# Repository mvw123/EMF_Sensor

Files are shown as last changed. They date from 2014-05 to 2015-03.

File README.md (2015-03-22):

EMF_Sensor
==========
Brief
-----
This is an open hardware design for an EMF sensor and transmitter circuit (sometimes known as a tone generator and detector, an ELF sensor, warbler or wire follower) which can be used to send a 2kHz audible tone down a wire with the transmitter and sense the presence of the wire with the receiver. It's main uses are for hidden wire and wire boundary detection. 

This is NOT for connection to LIVE mains or hazardous voltages - there are NO safety caps or safety barriers in the circuit. 

The circuit is created with Ki-CAD, an open source EDA tool for schematic capture and PCB layout. There are two boards in the design seperated by a snap off region. One for the transmitter, one for the receiver. The design should be battery powered from a 9v battery for each board.

The circuit is designed so that it can be used for other educational purposes and for general operational amplifier design. 

MVW

Details
-------
The PCB uses a mixture of through hole and SMD 1206 size components. These parts were chosen as a trade off between size and ease of fitting. Through hole axial leaded resistors and capacitors can be soldered onto the 1206 SMD pads if desired by soldering the parts vertically. SMD parts are used to reduce the PCB size which is the most costly part of the design. The PCB could have been smaller, but the aim is to allow beginners to be able to easily solder to the pads as well as experts. 

A Simetrix simulation file is included. Simetrix is a windows simulator which can be downloaded and used freely up to its node limit which is more than adequate for most situations. Please download and tweak it, i think you'll find some components are not entirely needed.

CAD B (Rev 0.02) [WORK IN PROGRESS] March 2014
-----------------------------
Schematic and PCB updated to fix bug stopping the wien bridge oscillator working
schematic and PCB updated to add an inline resistor for the voltage reference for one of the amplifiers
This version was edited using the 7-7-2013 BZR 4022 -stable build for windows which upgrades the PCB to a new type and renames its file extension. 
The Design would benefit from splitting into two seperate designs.
The circuit schematic pages need renaming to something more sensible. 
BOM not available

The design requires external parts not shown on the circuit schematic. eg:-
9v battery 
battery connector
2.5mm earphone adapter
wire - length TBD

CAD A (Rev 0.01) [NOT TESTED] March 2014
-----------------------------
First dev release, not tested - awaiting return of PCBs. 
Known bugs exist. 
The wien bridge oscillator is wired incorrectly.
The oscillator resistor/capacitor values need setting up (board released whilst the values are tweaked)

The board is being produced by oshpark which ships internationally. Price for the minimum 3 boards (in march 2014) is approximately $25

Ki-CAD created schematic, layout, gebers
Simetrix simulation file
BOM needs to be finalised.

Requires external parts not shown on the circuit schematic. eg
9v battery 
battery connector
2.5mm earphone adapter
wire - length TBD

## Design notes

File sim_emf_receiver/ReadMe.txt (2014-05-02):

simetrix simulation file
open file
select simulator menu, run.
This will show a graph of any voltage sensors shown on the circuit. 
you can place more voltage sensors with place, probe, voltage probe

MVW

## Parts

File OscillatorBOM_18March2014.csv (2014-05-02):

ref | value
BT201 | 9V_C
BT301 | 9V_C
C201 | 10n
C202 | 10n
C203 | 10n
C204 | 100uF
C205 | 100uF
C206 | 100uF
C301 | 0.01uF
C302 | 4.7pF
C303 | 220nF
C304 | 100uF
C305 | 1uF
C306 | 1uF
C307 | 1uF
C308 | 1.5nF
C309 | 20pF
P202 | CONN_2
P203 | CONN_2
P301 | CONN_2
P302 | CONN_2
R201 | 1k
R202 | 1k
R203 | 1k
R204 | 1k
R205 | 10k
R206 | 20k
R207 | 20k
R208 | 20k
R209 | 6.8k
R210 | 6.8k
R211 | 2k
R212 | 2k
R213 | 10R
R214 | 2k
R215 | 10R
R216 | 2k
R217 | 20k
R218 | 1k
R301 | 0R0
R302 | 1Meg
R303 | 22Meg
R304 | 4.7k
R305 | 1Meg
R306 | 1k
R307 | 22k
R308 | 47k
R309 | 1Meg
R310 | 100R
R311 | 1Meg
RV301 | 100k
SW201 | SPST
SW301 | SPST
U201 | TL072
U301 | TL072

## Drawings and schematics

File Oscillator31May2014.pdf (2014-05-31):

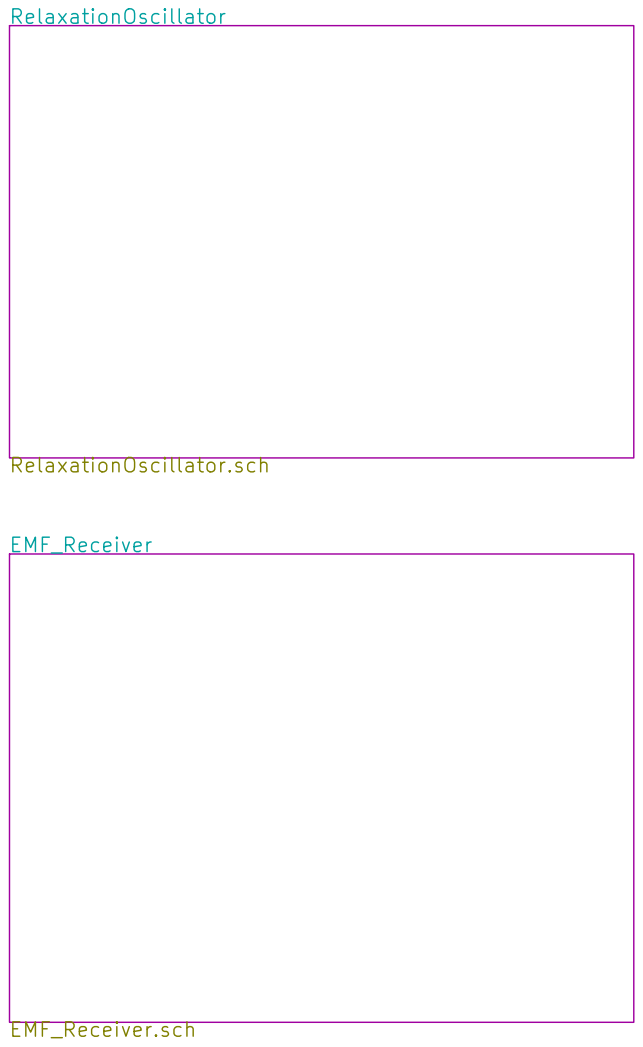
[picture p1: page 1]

Id: 1/3 Title: File: Oscillator.sch
Sheet: /

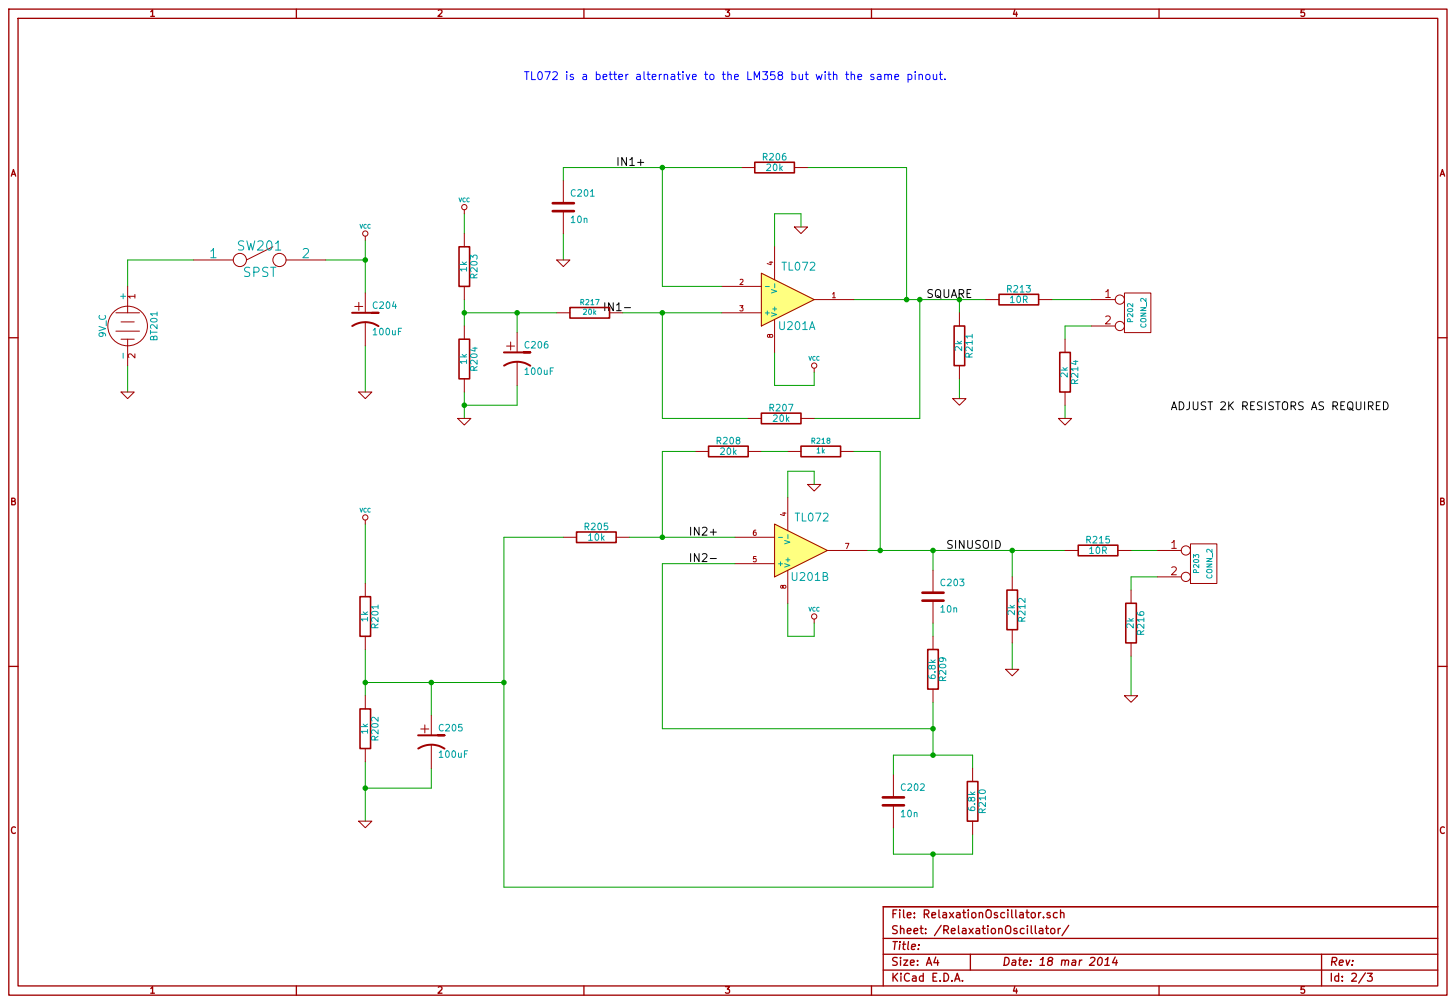
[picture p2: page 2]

TL072 is a better alternative to the LM358 but with the same pinout. VCC

Id: 2/3 Title: File: RelaxationOscillator.sch

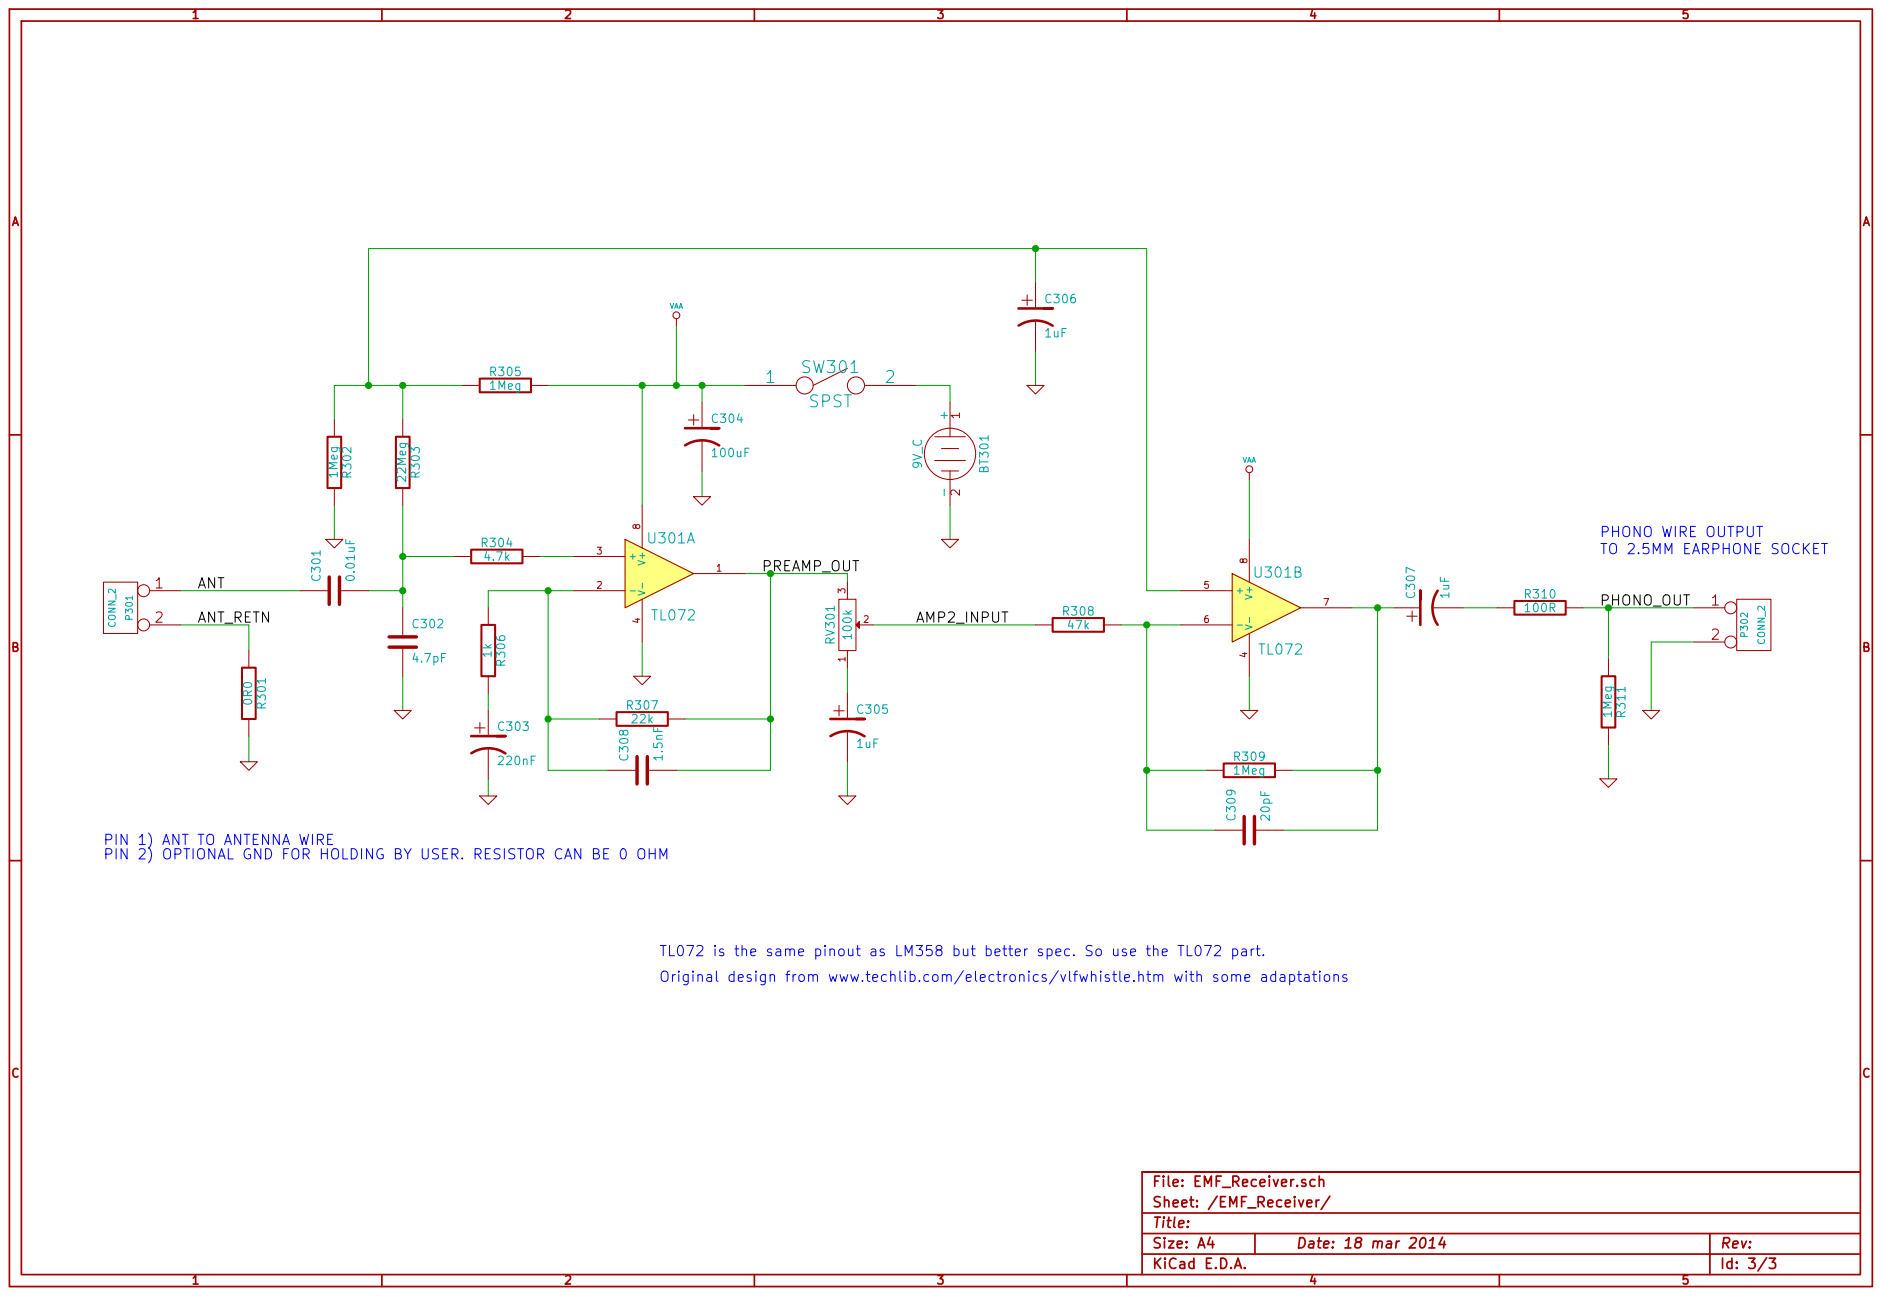
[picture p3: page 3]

Original design from www.techlib.com/electronics/vlfwhistle.htm with some adaptations 0R0 R301 1

PIN 1) ANT TO ANTENNA WIRE
PIN 2) OPTIONAL GND FOR HOLDING BY USER. RESISTOR CAN BE 0 OHM

Id: 3/3 Title: File: EMF_Receiver.sch
Sheet: /EMF_Receiver/

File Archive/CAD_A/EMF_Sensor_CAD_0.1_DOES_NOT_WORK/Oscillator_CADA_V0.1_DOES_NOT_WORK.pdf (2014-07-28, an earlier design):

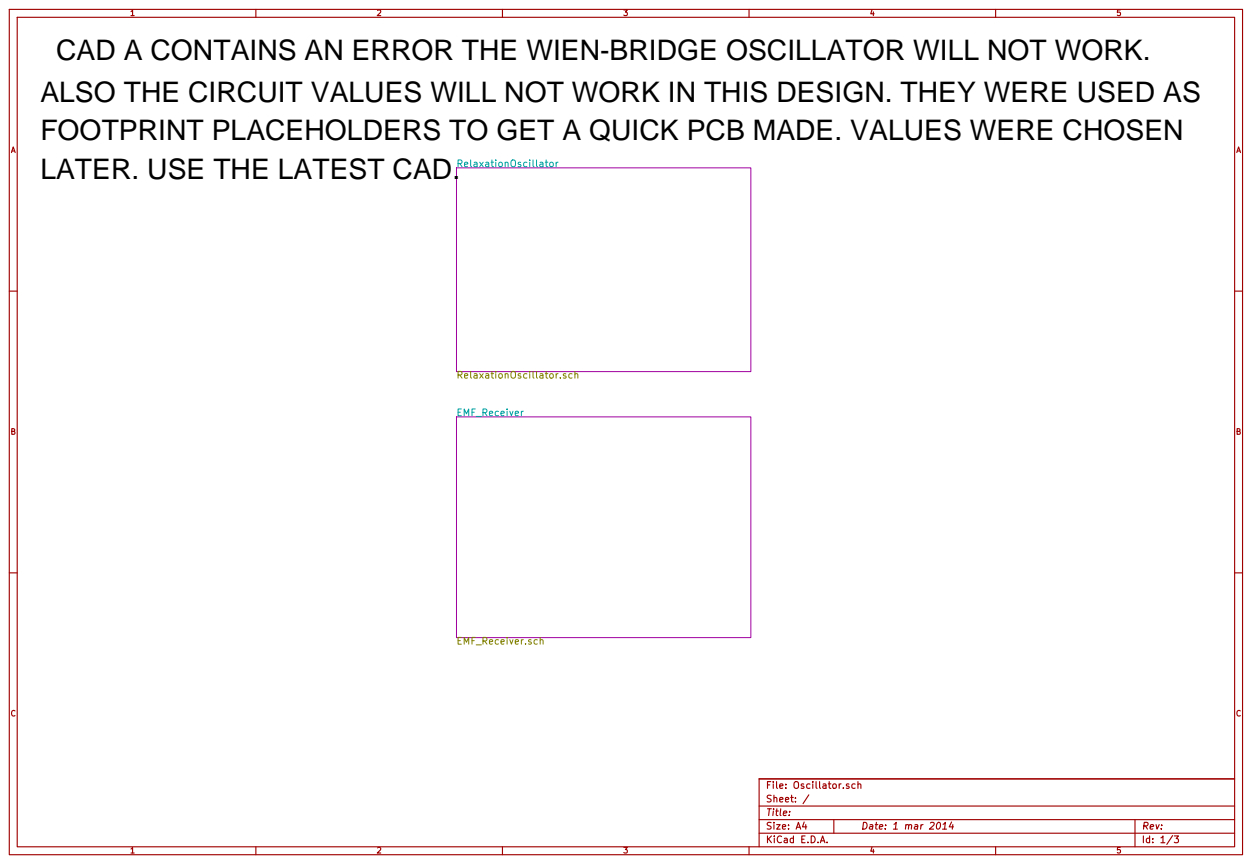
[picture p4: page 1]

Id: 1/3 Title: File: Oscillator.sch
Sheet: /

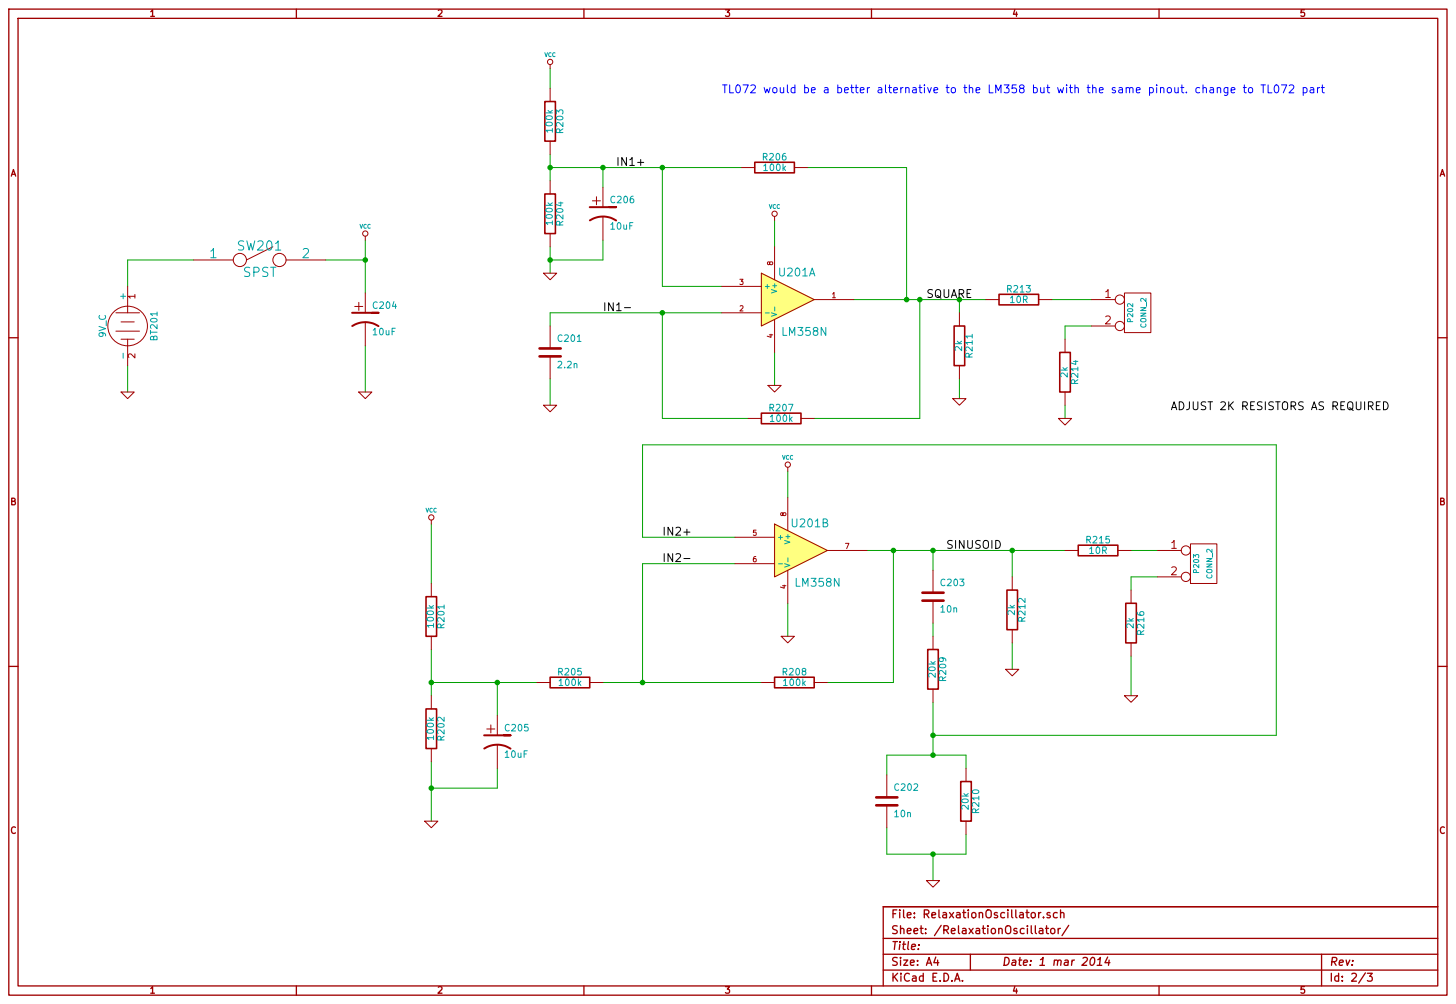
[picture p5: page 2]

TL072 would be a better alternative to the LM358 but with the same pinout. change to TL072 part VCC

Id: 2/3 Title: File: RelaxationOscillator.sch
Sheet: /RelaxationOscillator/

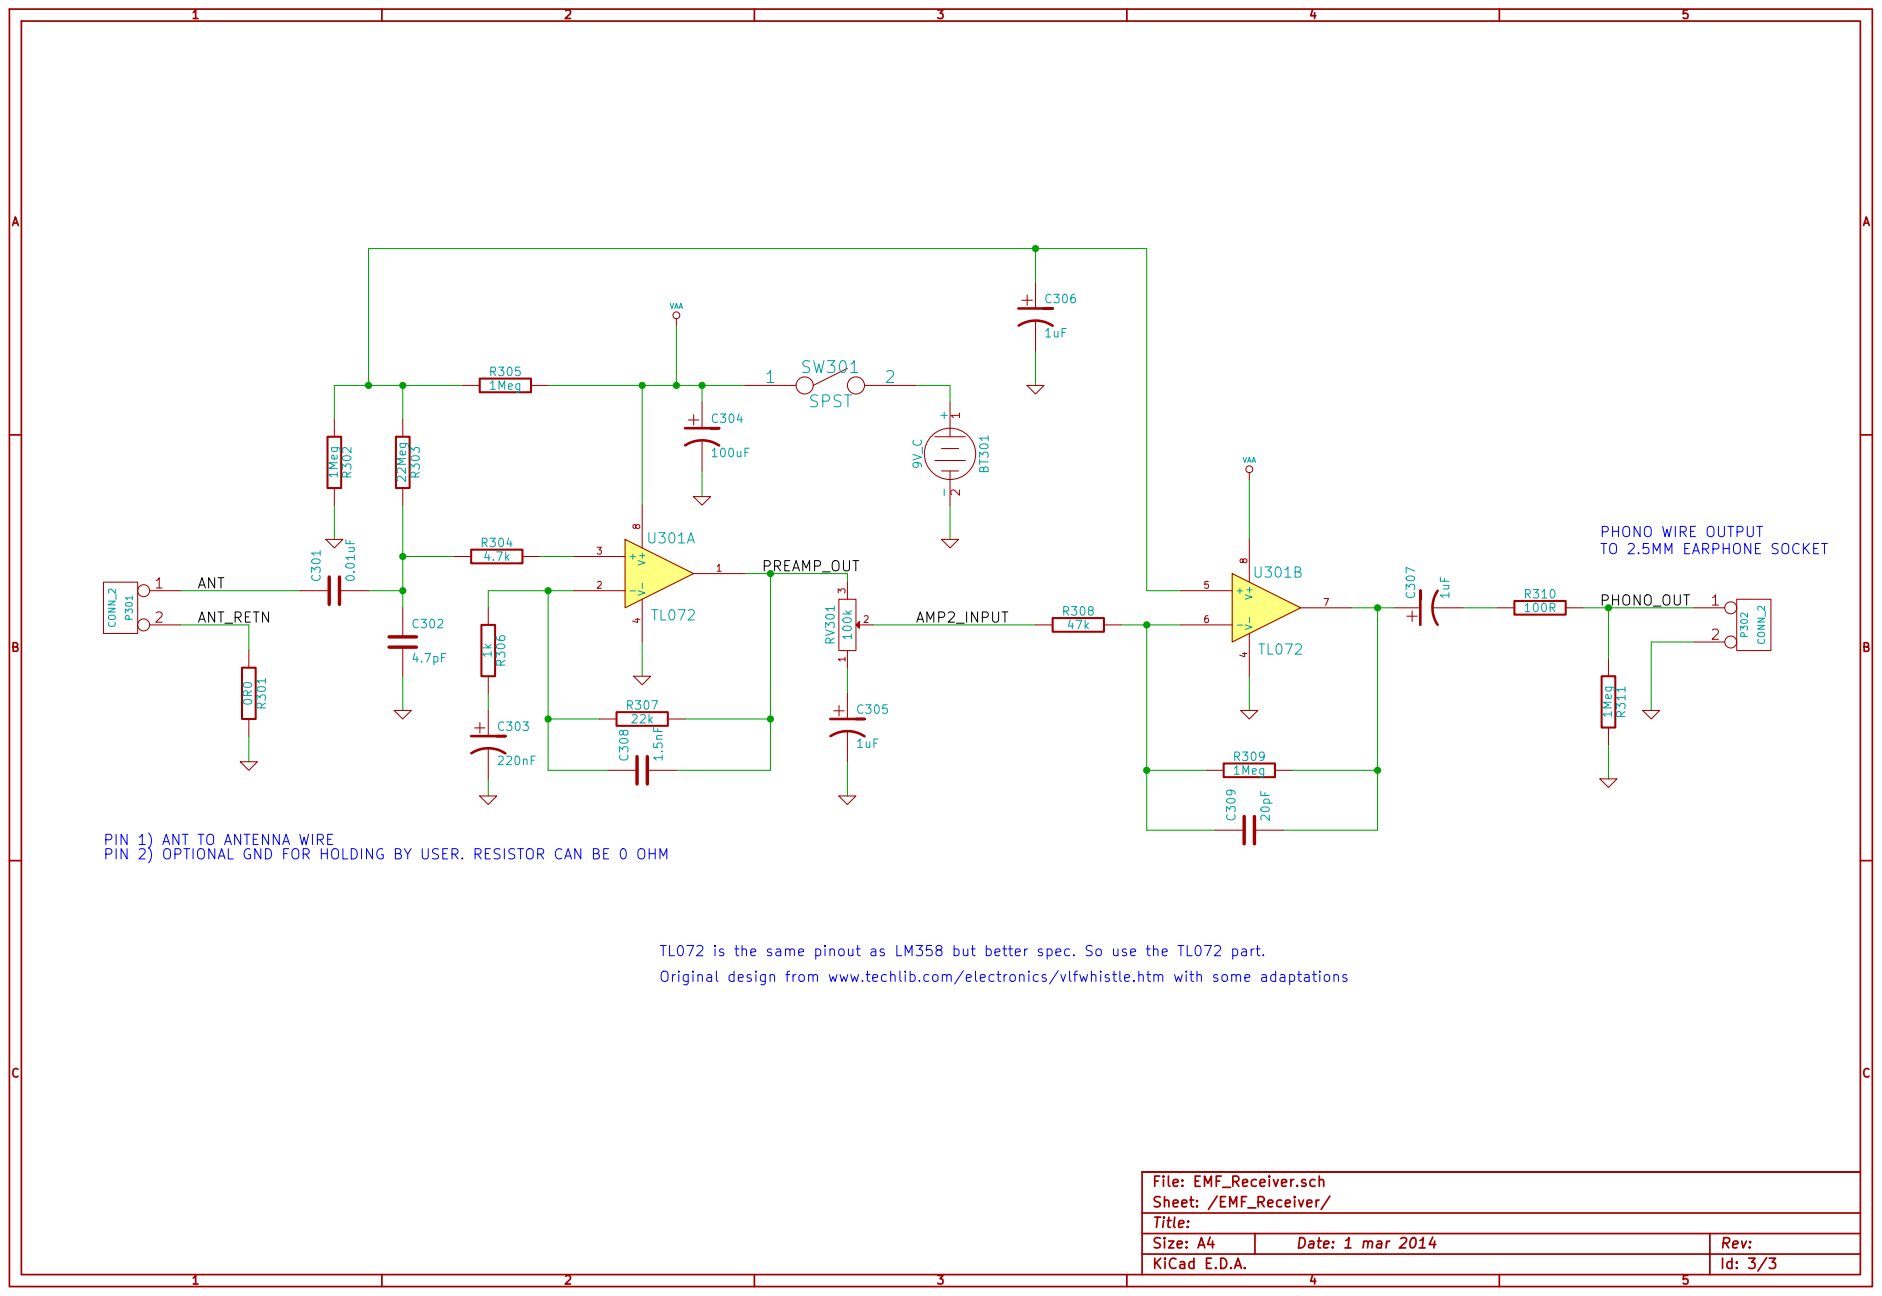
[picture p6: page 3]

Original design from www.techlib.com/electronics/vlfwhistle.htm with some adaptations 0R0 R301 1

PIN 1) ANT TO ANTENNA WIRE
PIN 2) OPTIONAL GND FOR HOLDING BY USER. RESISTOR CAN BE 0 OHM

Id: 3/3 Title: File: EMF_Receiver.sch
Sheet: /EMF_Receiver/

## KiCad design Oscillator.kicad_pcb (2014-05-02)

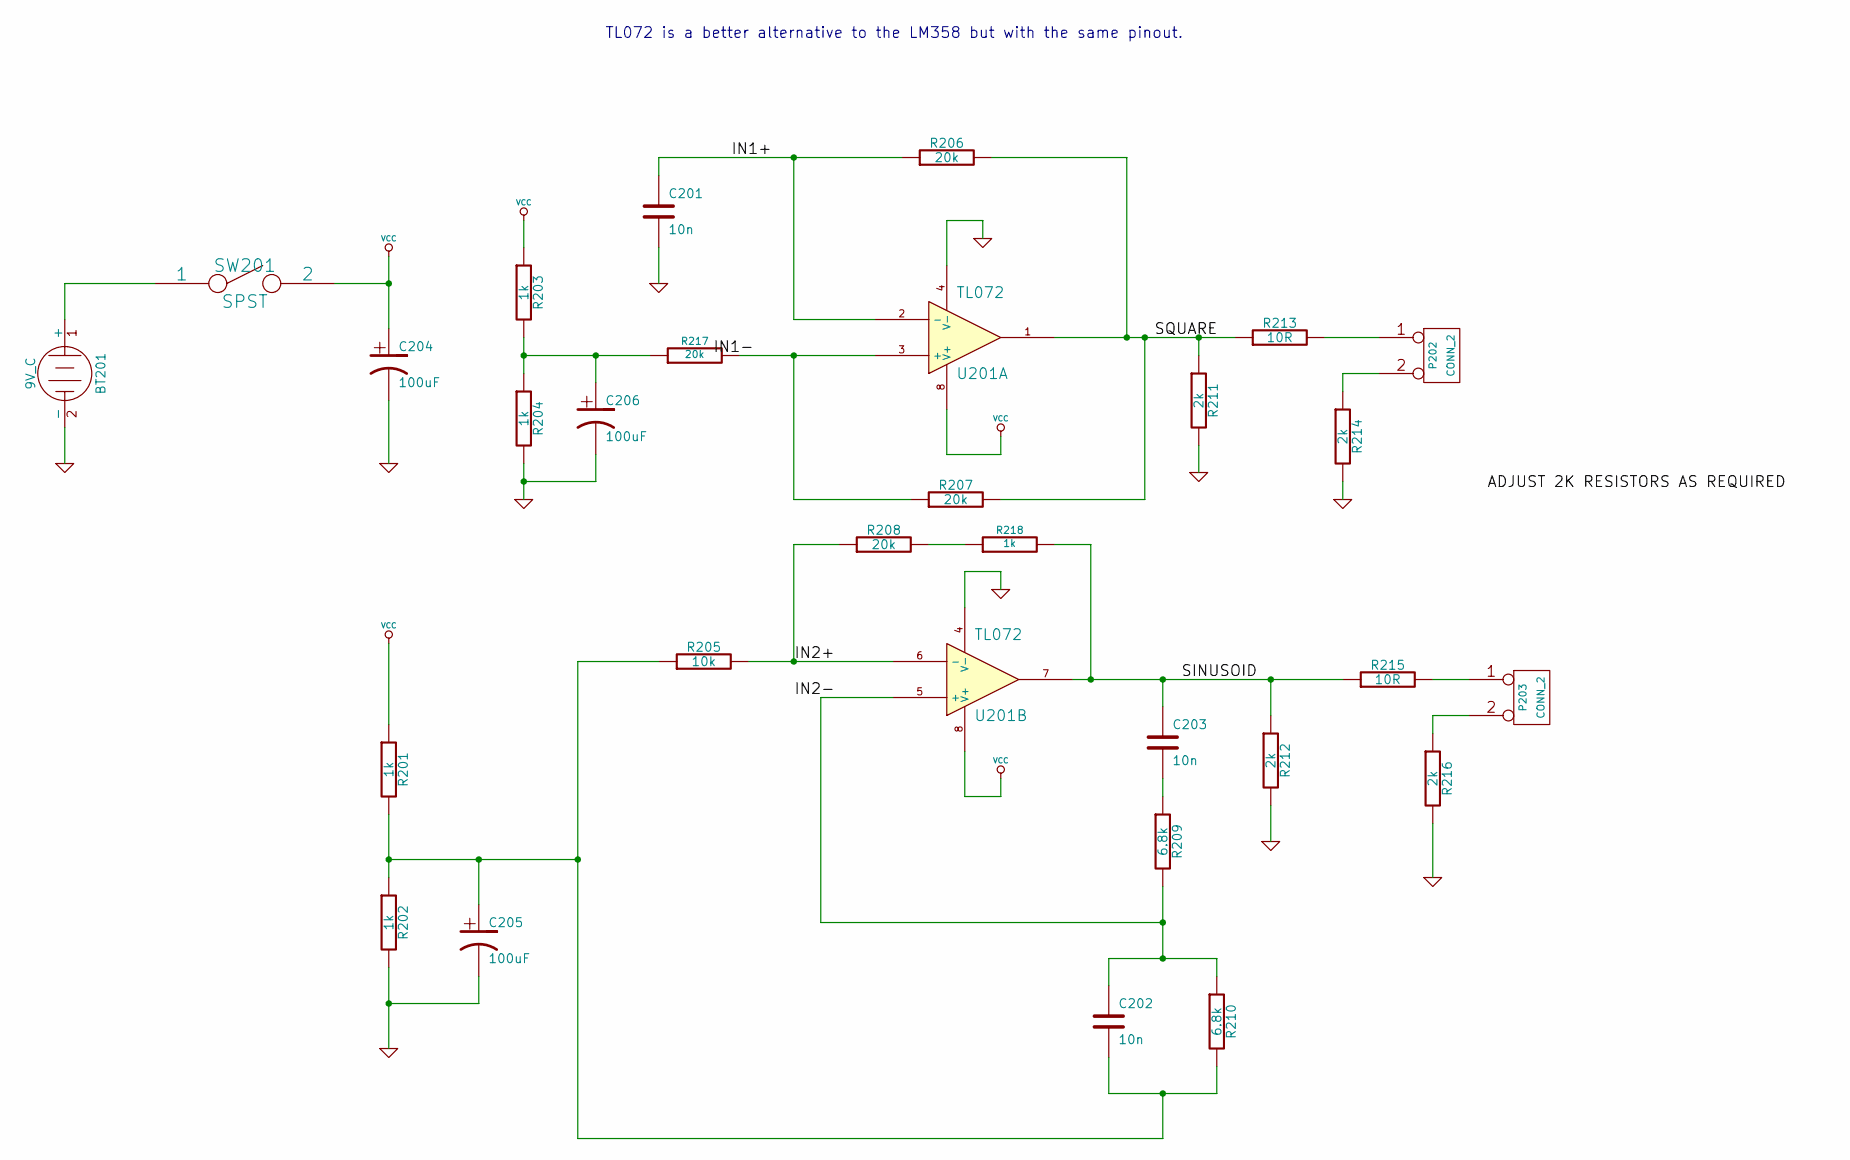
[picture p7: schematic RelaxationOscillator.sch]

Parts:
BT201: 9V_C
C201, C202, C203: 10n
C204, C205, C206: 100uF
P202, P203: CONN_2
R201, R202, R203, R204: 1k
R205: 10k
R206, R207, R208: 20k
R209, R210: 6.8k
R211, R212, R214, R216: 2k
R213, R215: 10R
R217: 20k
R218: 1k
SW201: SPST
U201: TL072

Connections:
/RelaxationOscillator/IN1+: C201.1, R206.1, U201.2 (-)
/RelaxationOscillator/IN2+: R205.2, R208.1, U201.6 (-)
/RelaxationOscillator/IN2-: C202.1, R209.2, R210.1, U201.5 (+)
/RelaxationOscillator/SINUSOID: C203.1, R212.1, R215.1, R218.2, U201.7
/RelaxationOscillator/SQUARE: R206.2, R207.2, R211.1, R213.1, U201.1
GND: BT201.2 (-), C201.2, C204.2, C205.2, C206.2, R202.2, R204.2, R211.2, R212.2, R214.2, R216.2, U201.4 (V-); also elsewhere on the board
unnamed: C203.2, R209.1
unnamed: R207.1, R217.2, U201.3 (+)
unnamed: P202.2 (PM), R214.1
unnamed: P203.1, R215.2
unnamed: P203.2 (PM), R216.1
unnamed: R208.2, R218.1
unnamed: C206.1, R203.2, R204.1, R217.1
unnamed: BT201.1 (+), SW201.1
unnamed: P202.1, R213.2
unnamed: C202.2, C205.1, R201.2, R202.1, R205.1, R210.2
VCC: C204.1, R201.1, R203.1, SW201.2, U201.8 (V+)

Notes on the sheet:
TL072 is a better alternative to the LM358 but with the same pinout.

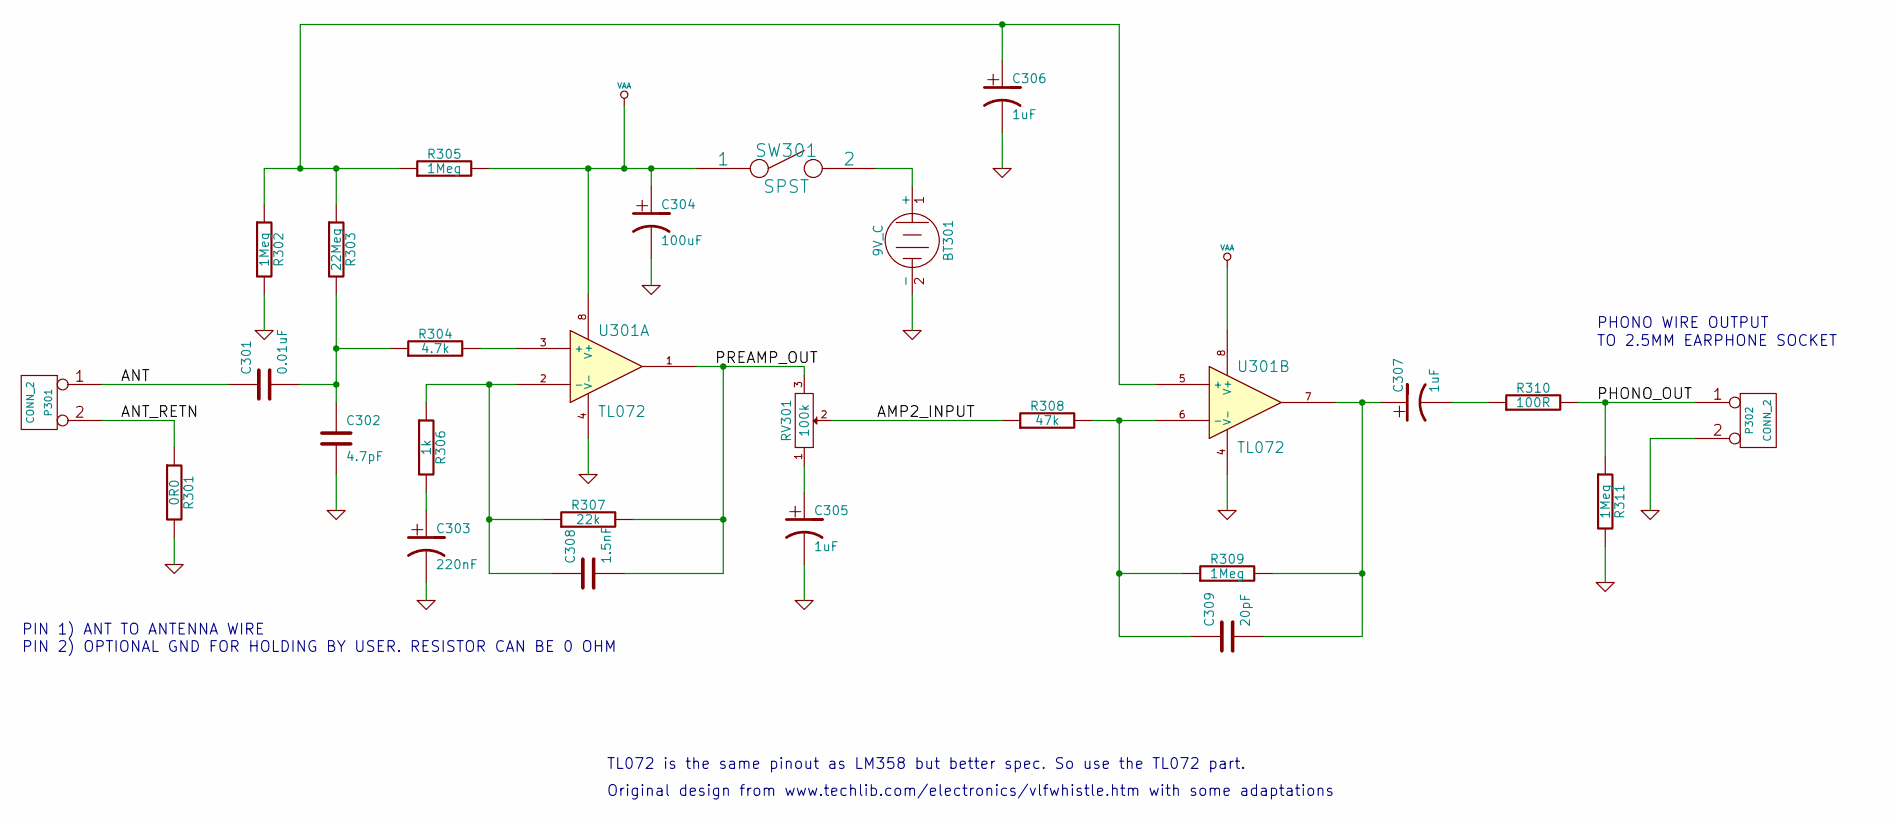
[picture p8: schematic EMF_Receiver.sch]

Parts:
BT301: 9V_C
C301: 0.01uF
C302: 4.7pF
C303: 220nF
C304: 100uF
C305, C306, C307: 1uF
C308: 1.5nF
C309: 20pF
P301, P302: CONN_2
R301: 0R0
R302, R305, R309, R311: 1Meg
R303: 22Meg
R304: 4.7k
R306: 1k
R307: 22k
R308: 47k
R310: 100R
RV301: 100k
SW301: SPST
U301: TL072

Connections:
/EMF_Receiver/AMP2_INPUT: R308.1, RV301.2
/EMF_Receiver/ANT: C301.1, P301.1
/EMF_Receiver/ANT_RETN: P301.2 (PM), R301.1
/EMF_Receiver/PHONO_OUT: P302.1, R310.2, R311.1
/EMF_Receiver/PREAMP_OUT: C308.2, R307.2, RV301.3, U301.1
GND: BT301.2 (-), C302.2, C303.2, C304.2, C305.2, C306.2, P302.2 (PM), R301.2, R302.2, R311.2, U301.4 (V-); also elsewhere on the board
unnamed: C305.1, RV301.1
unnamed: C307.2, R310.1
unnamed: C307.1, C309.2, R309.2, U301.7
unnamed: C301.2, C302.1, R303.2, R304.1
unnamed: C303.1, R306.2
unnamed: C306.1, R302.1, R303.1, R305.1, U301.5 (+)
unnamed: R304.2, U301.3 (+)
unnamed: BT301.1 (+), SW301.2
unnamed: C309.1, R308.2, R309.1, U301.6 (-)
unnamed: C308.1, R306.1, R307.1, U301.2 (-)
VAA: C304.1, R305.2, SW301.1, U301.8 (V+)

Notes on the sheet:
PHONO WIRE OUTPUT
TO 2.5MM EARPHONE SOCKET
PIN 1) ANT TO ANTENNA WIRE PIN 2) OPTIONAL GND FOR HOLDING BY USER. RESISTOR CAN BE 0 OHM
Original design from www.techlib.com/electronics/vlfwhistle.htm with some adaptations
TL072 is the same pinout as LM358 but better spec. So use the TL072 part.

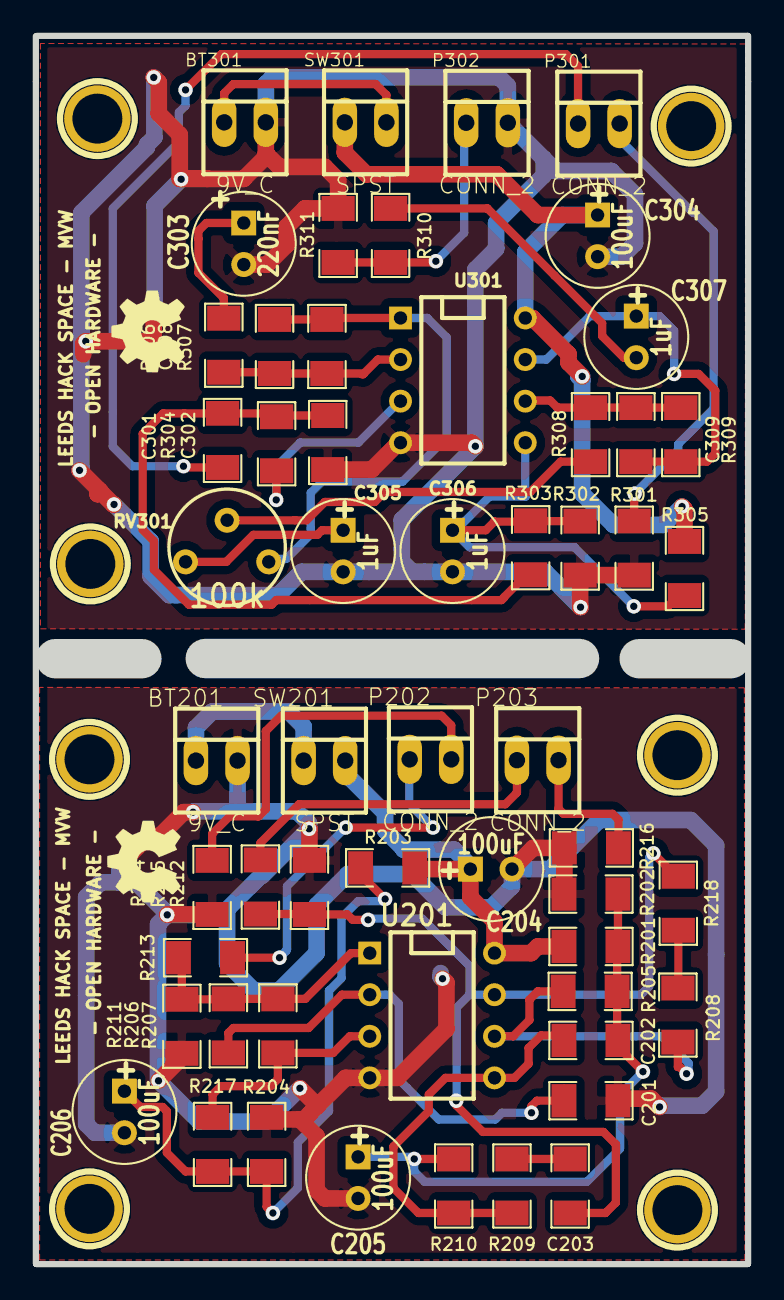
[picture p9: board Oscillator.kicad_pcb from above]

Board: 2 copper layers, 43.5 x 75.0 mm, 62 parts (0 on the bottom side), 33 nets.

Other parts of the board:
1PIN, 1PIN#2, 1PIN#3, 1PIN#4, 1PIN#5, 1PIN#6, 1PIN#7: P***; 1pin

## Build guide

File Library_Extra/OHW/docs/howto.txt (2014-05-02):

How to make your own:
---------------------

Watch / read this first:

* http://www.kicad-pcb.org/display/KICAD/Videos+by+zupnikal

The last two videos should be helpful for how to create a custom .emp file from images.

* http://www.re-innovation.co.uk/web12/index.php/en/blog-75/230-adding-logo-to-kicad

If you use linux (which you should), you don't have to use the online-scaler. Just use the scripts!

---

* Create a folder to hold your new footprint library.
* Copy the scripts 'make_lib.sh' and 'scale.pl' into that folder.
* Make sure these files are executable (chmod u+x ...).
* Copy your custom .emp file into that foler.

* Run the 'make_lib.sh' script as follows:

./make_lib.sh input-file.emp lib-name.mod START END

START and END are placeholders for positive integer numbers (1,2,3...) that determine
the range of created footprint sizes. The units are metric (mm).

The 'lib-name.mod' file will show up in the 'lib' sub-folder. Add it to your pcbnew
library settings as usual.

Footprints that are created for back-layers are automagically mirrored horizontally.
To place them onto a back-layer, hover the mouse-pointer over them and press 'f' for 'flip'.

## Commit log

2014-03-09 First Commit of CAD A released for PCB manufacture
    First commit of the CAD A released for PCB manufacture. Includes the
    gerbers. no BOM is output here since it is liable to change. Also the
    simulation files are not present, they will be added later.
    [EMF_Receiver.sch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]
2014-03-16 Updated schematic and moved files to new location
    Corrected errors in the schematic which will affect the PCB. PCB not
    changed yet. Updated resistor and cap values and changed amp type to
    comply with the simulations. The CAD A wien-bridge PCB will not
    oscillate. The relaxation oscillator will oscillate but the new values
    are required. The new schematic adds new components to the circuit which
    need putting into the PCB.
    [EMF_Receiver.sch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]
2014-03-16 Added notes to schematic pdf. moved a few files around and deleted others
    added notes to the schematic pdf indicating cad A is faulty AND MOVED A
    FEW OUTPUT FILES AROUND
    [Oscillator-Back.gbl, Oscillator-Front.gtl, Oscillator-Mask_Back.gbs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]
2014-03-16 PCB updated from schema. Using new Kicad version
    Updated the PCB with the schematic updates. Using the newer kicad
    version for windows. 7-7-2013 BZR 4022 -stable
    The old PCB file has been updated to the new version.
    [EMF_Receiver.sch, Oscillator.brd, Oscillator.kicad_pcb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]
2014-05-02 added tone generator and detector description of a device found on maplin.co.uk
    added tone generator and detector description of a device found on maplin.co.uk
    eg the n74cc
    http://www.maplin.co.uk/p/cable-tracker-with-tone-generator-n74cc
2014-05-02 committing some library updates and sims along with a bom
    committing some library updates and sims along with a bom.
    These were updated quite a while ago so i'm not sure if this information
    is accurate or correct.
    [EMF_Receiver.sch, Oscillator.kicad_pcb, OscillatorBOM_18March2014.csv]
2014-05-31 Created pdf of current design
2014-07-28 Added notes to oscillator page. no other changes
    Added notes to oscillator page. no other changes
    [EMF_Receiver.sch, Oscillator.sch, RelaxationOscillator.sch]
2014-08-31 few basic updates
    few basic updates
    [EMF_Receiver.sch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]
